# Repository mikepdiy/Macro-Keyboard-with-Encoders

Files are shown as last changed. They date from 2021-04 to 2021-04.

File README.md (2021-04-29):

<h1> Macro-Keyboard-with-Encoders</h1>
<br>
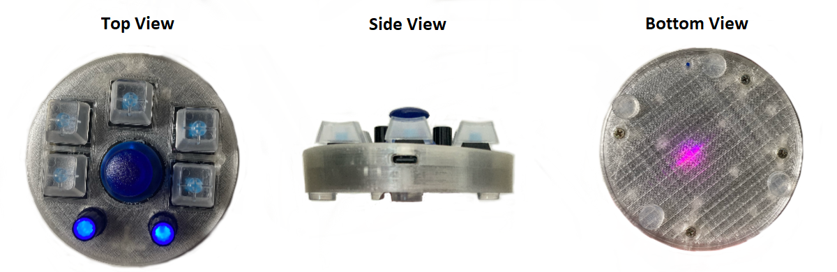
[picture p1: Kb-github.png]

<br>
<h3> Introduction and background </h3>
<br>
<br>
The idea to make this macro keyboard came to me when I was learning CAD and I found myself needing to use multiple keys shortcuts that included also middle mouse button presses for orbiting around the 3D object.
That was the moment when I went out to search for an accessory that can ease my life but to my surprise what was available on the market was also quite expensive to the point that I felt it was not worth it as I am not a CAD/CAM designer by trade but I wanted to learn a skill to aid my maker skill set. So what's the next thing a maker will do ? Indeed a maker will make it's own spin of an accessory. <br>
When making this keyboard I wanted to build something that fulfilled a few requirements :
<ul>
  <li> Easy to use for any user with out without technical knowledge</li>
  <li> Easy to set and use on any common Operating System ( Windows/MacOS/Linux ... ) </li>
  <li> No special software required to change the key's functionality</li>
  <li> Multiple key presses combined with mouse key presses on a single key </li>
  <li> Multiple ways of controlling the mouse pointer</li>
  <li> Open source as much as possible at least on the software side </li>
  <li> Hackable for the user that wants to do that without any special tools at least for the software side</li>
  <li> 3D printable case for the users that want to customize it</li>
  <li> Open source STL file of the board so the users can build their own spin of the case </li>
</ul>

<h3> What does this keyboard offer ?</h3>

<h4> Hardware </h4>
<ul>
  <li> 5 x MX Key Blue switches ( soldered to the PCB)</li>
  <li> 2 x Rotary encoders with 24 positions per rotation, push button function(click) if it is pressed and a blue led illumination. Left is for horizontal mouse pointer movement and Right is vertical mouse pointer movement</li>
  <li> 1 x Analog Joystick with push button function </li>
  <li> Type-C USB port that works correctly with type-C to type-C cables or type-C to USB-A cables </li>
  <li> Reset button on the bottom to allow quick software upgrade with drag and drop files</li>
  <li> Lightweight Design</li>
</ul>
<br>
<h4> Software </h4>
 <ul>
  <li> Based on open source bootloader and libraries </li>
  <li> Easy configuration by editing a text file for each individual button</li>
  <li> It can act as a <b>shortcut keyboard</b> => no matter how long you press the button it only clicks once </li>
  <li> It can act as a <b>keyboard</b> => as long as you keep a button pressed the programmed buttons in the configuration file will be pressed; example : in Fusion360 oribiting around a 3D object is done by holding pressed SHIFT+Mouse Middle Button and moving the mouse pointer; this can be achieved by keeping pressed one button on the macro keyboard and moving: your own mouse, the joystick on the macro keyboard or the rotary encoders  </li>
  <li> 2 firmware versions, one for <b> Shortcut keyboard </b> functionality and one for <b> Keyboard functionality </b> .</li>
  <li> In both firmware versions the keyboard can also type text for you i.e.: in case you want to use to type frequently used phrase or passowrd <b>(It's NOT SAFE to save your password in a shortcut keyboard and use it like this but sometimes convenience wins and the option is here but it's your choice if you want to use it or not)</b></li>
  <li> Access to the source code that was written for the Arduino IDE but it can be used in other IDE's</li>
  <li> .uf2 firmware releases with the original firmware released by me but also future updates in case there will be bugs that need to be fixed.</li>
  <li> For developers, this board also comes with exposed SWD interface that can be used if you need to </li>
  </ul>
  
 <h4> Included in this Repo </h4> 
  <ul>
    <li> Schematic </li>
    <li> Code for Arduino </li>
    <li> Bootloader </li>
    <li> .step board 3D file </li>
    <li> .stl 3D printable case that can be printed with FDM printers with 0.2mm layer height, 0.4mm nozzle and 30% infill using PLA </li>
  </ul>

  <h4> Tempted to grab one for yourself ? </h4>

  
  
<h4> Credits for the software side </h3>
  <ul>
  <li> <a href="https://github.com/adafruit">Adafruit Industries</a> - for their amazing work and tools that they provide for anyone to learn and enchance their skills</li>
  <li> <a href="https://github.com/danionescu0/arduino">Danionescu0</a> - for the helpful work done on parsing text files from an external storage in very short time </li>
  <li> Creators and contribuitors of the <a href="https://github.com/thomasfredericks/Bounce2">Bounce 2 library</a></li>
  <li> Creators and contribuitors of the <a href="https://github.com/mprograms/SimpleRotary">Simple Rotary library</a></li>
  <li> The creator of <a href="https://github.com/blurfl/makeUF2-tool/releases">MakeUF2-tool</a> </li>
 </ul>

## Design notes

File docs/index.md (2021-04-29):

## Welcome to the MacroKB web resources page

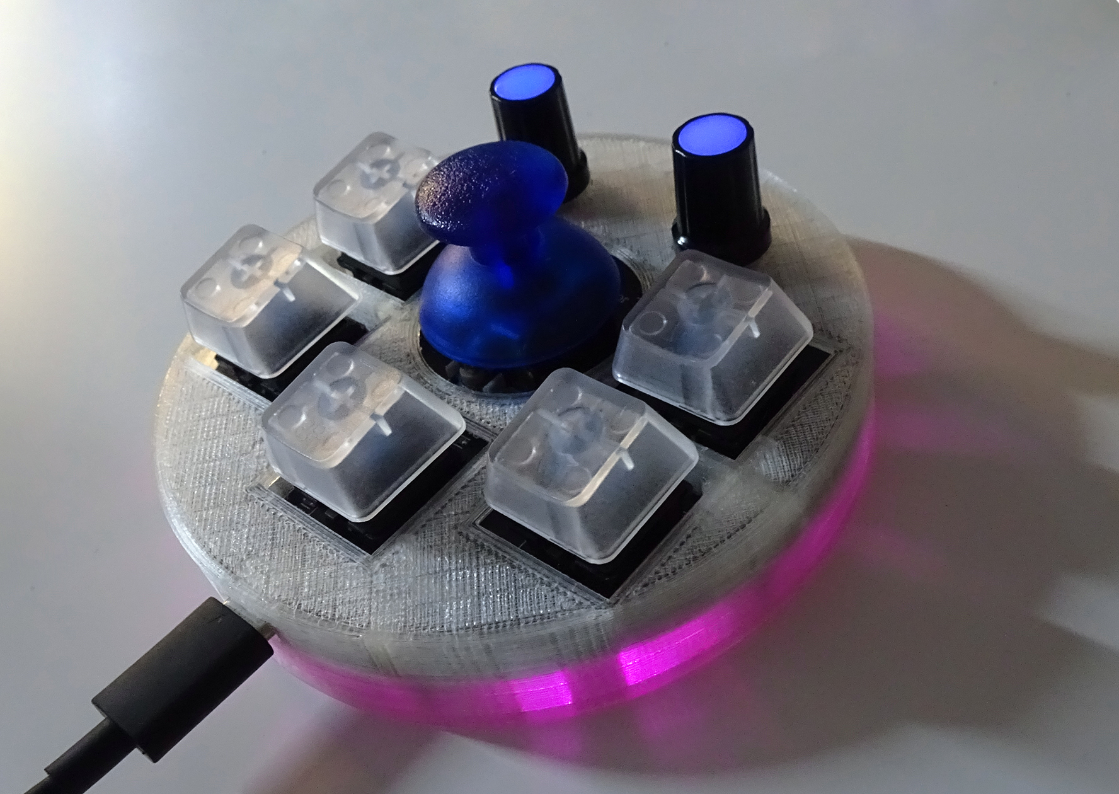
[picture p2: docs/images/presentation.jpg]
Presentation image


## The user manual can be found  [here](manual.md).

### More details are present in the Github repository [here](https://github.com/mikepdiy/Macro-Keyboard-with-Encoders/)

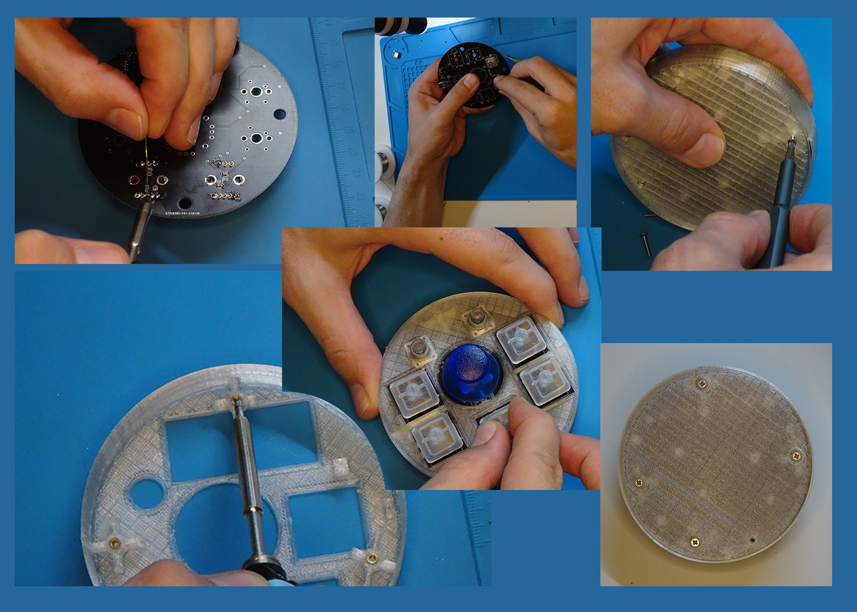
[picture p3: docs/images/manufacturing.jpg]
Manufacturing image


  <h4> Tempted to grab one for yourself ? </h4>

  

### More details to be added soon

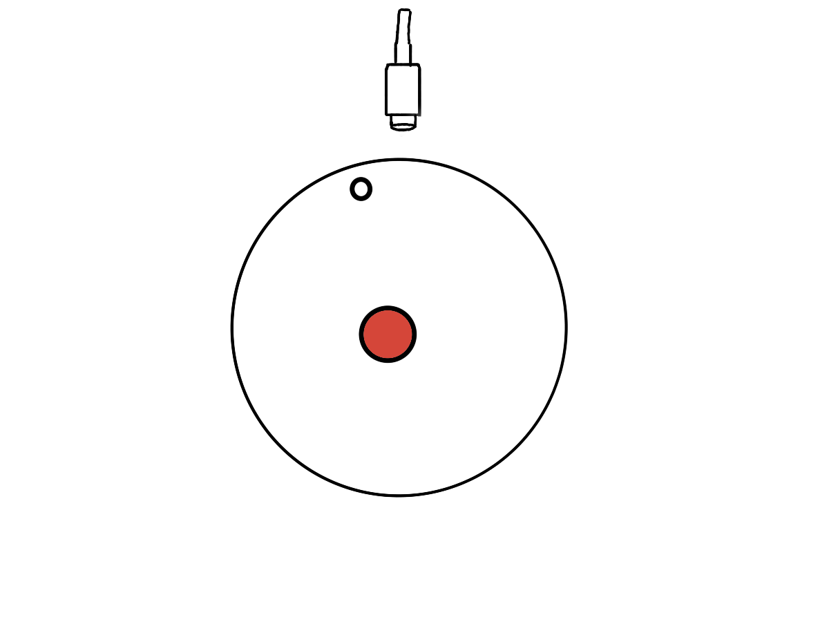
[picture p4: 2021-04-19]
docs/images/Red.png

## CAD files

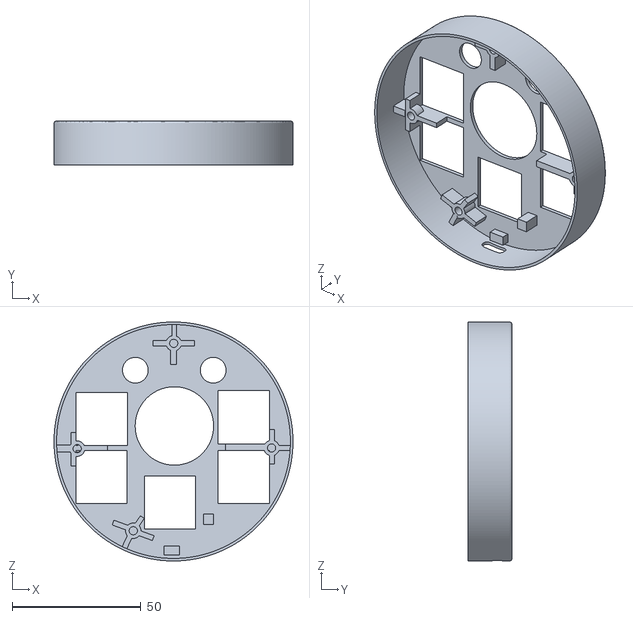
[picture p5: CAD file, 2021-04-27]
Case files/STL/top_case.stl
93.0 x 17.2 x 93.0

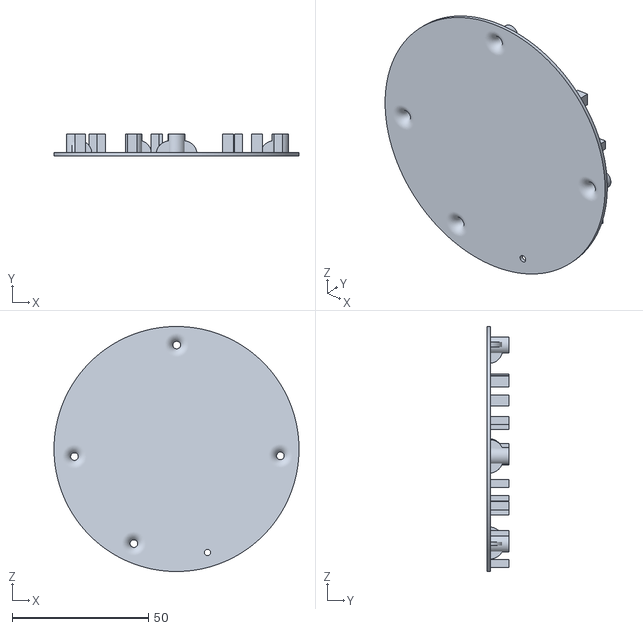
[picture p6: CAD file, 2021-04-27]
Case files/STL/bottom_case.stl
90.0 x 8.00 x 90.0

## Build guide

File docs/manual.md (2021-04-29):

## Thank you for supporting our project and deciding to grab our very first macro keyboard !

Overall image

```markdown
External Features / Components :

The macro keyboard has the following interfaces : 

    5 x MX-Key Blue switches

    1 x Analog Joystick (with switch functionality , it acts as a button when you press it )

    2 x Rotary Encoders (with switch functionality , it acts as a button when you press it )

    1 x Reset Button 

    1 x Type-C USB connector ( receptacle )

Supported Operating Systems : 

Any operating system that supports a keyboard can be used with our keyboard.
    
Works also with type-c to type-c cables ! (Who thought this is a feature ? :)) ) 
```
### Above Image

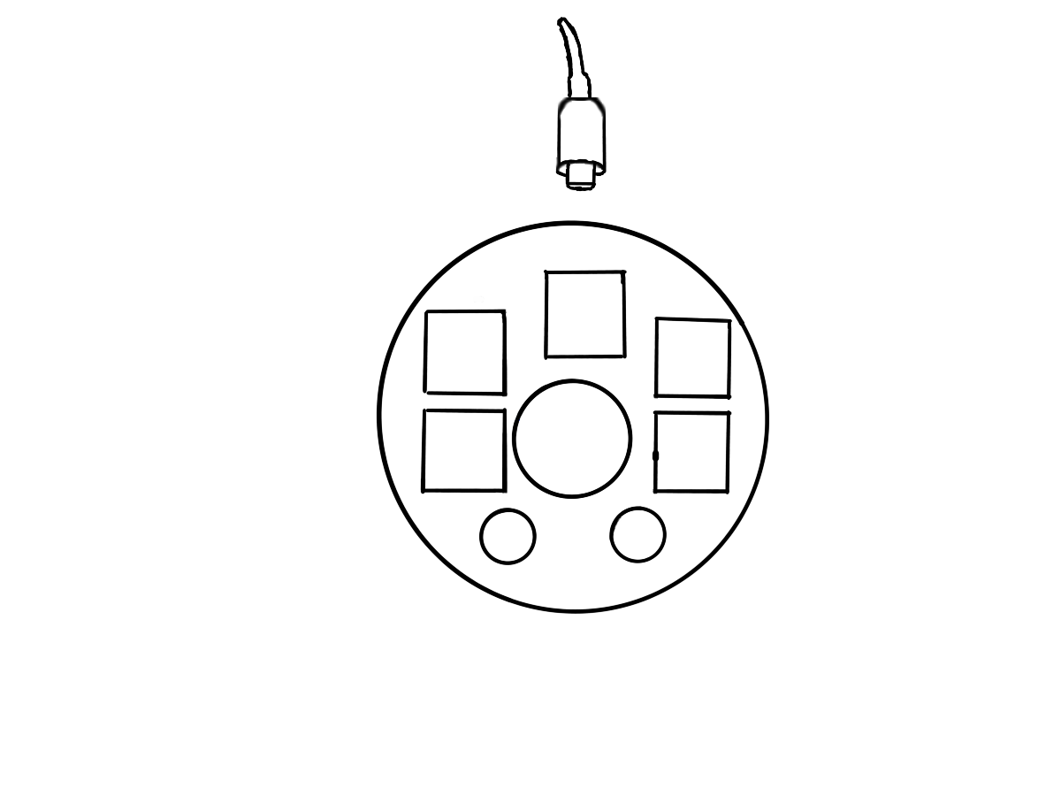
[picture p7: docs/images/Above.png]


### Encoders 

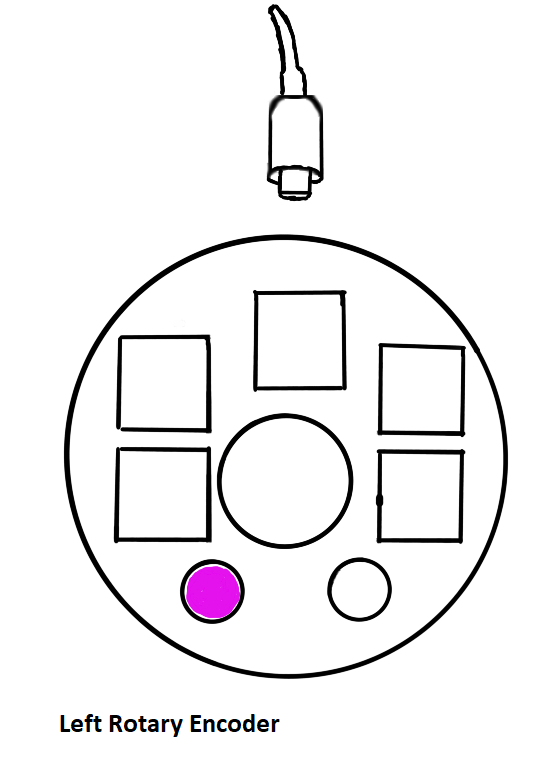
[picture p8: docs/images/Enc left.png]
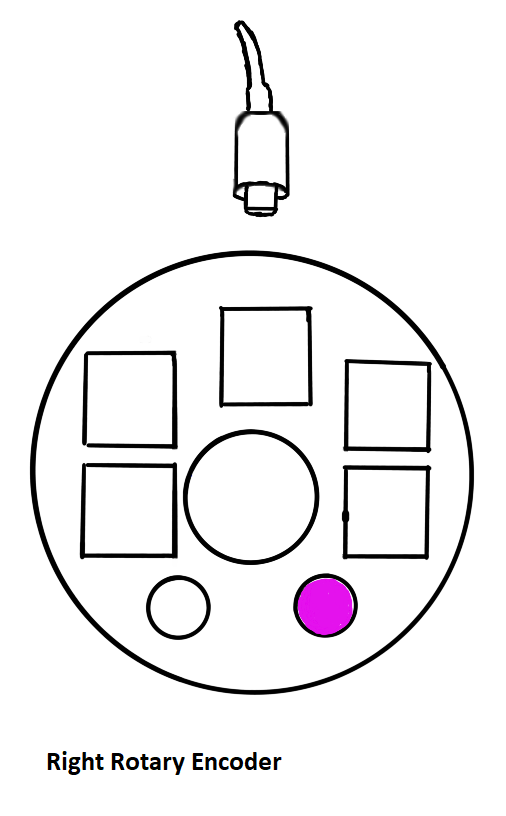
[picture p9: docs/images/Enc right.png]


```markdown
The Left Rotary Encoder moves the mouse pointer `Horizontally`. 
The Right Rotary Encoder moves the mouse pointer `Vertically`. 
```

### How to change the buttons configuration/functionality :

In order to use our macro keyboard you have to configure each button to do what you want it to do. This is actually very simple and it is a process you only have to do once . In case anything goes wrong, you can always restore the original files and start again.

### Configuration Steps : 

1. press the configuration button ( top middle button) and while you are keeping the button pressed, insert the usb cable that is connected to your pc.  
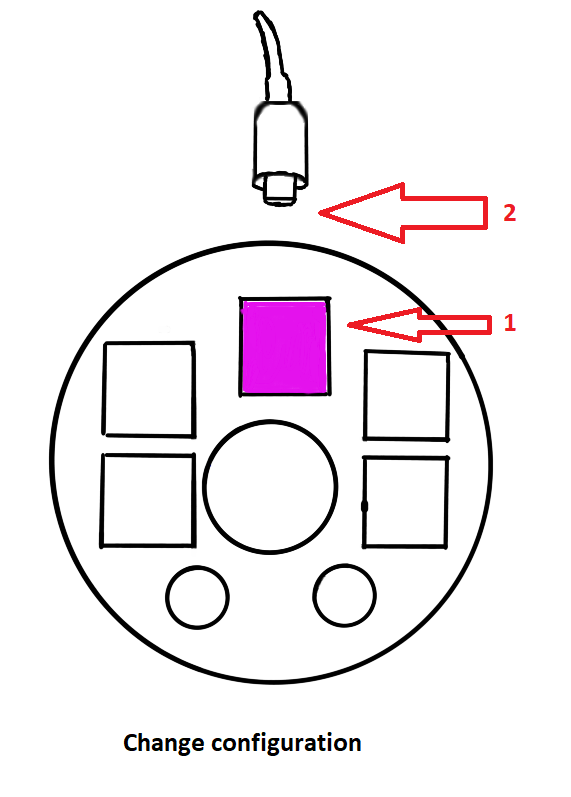
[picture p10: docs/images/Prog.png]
  

2. once the cable is connected to your pc the configuration button can be released and in a few seconds a new drive will appear in your file manager or “Computer” ( just like a new USB stick appears when you connect it to your computer).See the image below as an example :  
USB Drive  

 *If this is the first time you are connecting the keyboard to your computer, it might take a short while to install drivers .* 
 
 3.By opening and accessing the new disk that just appeared you will see a list of 6 ( six) text files that are named corresponding to the key position that each one of them controls. Please see the image below :  
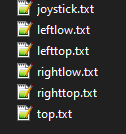
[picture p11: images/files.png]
files Drive
   
 
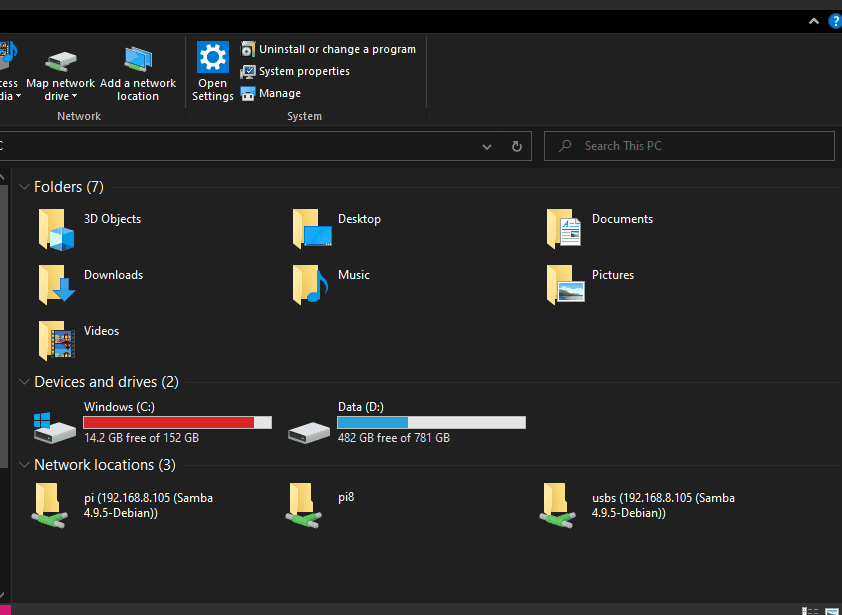
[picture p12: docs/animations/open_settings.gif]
Open Settings
  

 4. In order to change the configuration, you will have to open the file and edit the function(s) that the button will perform . Let’s open the file by double clicking on the button name.  
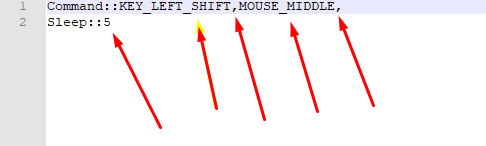
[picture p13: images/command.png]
Command example
   
 
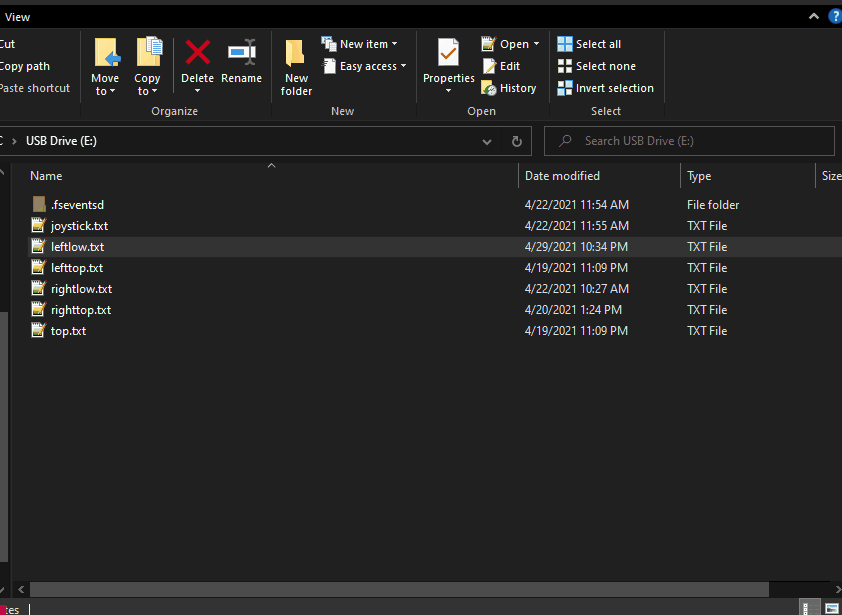
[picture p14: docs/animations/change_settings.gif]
Edit a command
    
 The first row starts with *Command::* and after that we have each key separated by comma ``` , ``` please put a comma ``` , ``` after each command and take note that the commands are executed in order.  We will explain the commands possible separately in the Keyboard Commands chapter. You can easily set 3 keys to be pressed at once but more than that is also possible.  

The commands can also be combined with letters ; for example : ``` Command:: KEY_LEFT_CTRL,p, ``` will bring up the print menu in Windows and Linux while ```Command:: KEY_LEFT_ALT,p,``` will open the print menu on MacOs.  

The example below does the following : Simulate SHIFT key press and while SHIFT is pressed it will simulate the press of the Mouse Middle key , this is what is needed for Autodesk Fusion 360 to allow orbiting around a 3D file.   

The second row starts with *Sleep::* and this allows you to set a very short break that is counted in milliseconds in case your computer doesn’t register all the key presses that you have set. The Sleep function just allows a short amount of time for the computer to register each button press and it should be used like this :  

```markdown
Command::KEY_LEFT_SHIFT,
Sleep::5
Command::MOUSE_MIDDLE,
```
#### Don’t use the *Sleep::* function unless you need it !

### Other examples :
 
Copy Functionality on Windows : 

```markdown
Command::KEY_LEFT_CTRL,
c
```

Paste Functionality for Windows : 
```markdown
Command::KEY_LEFT_CTRL,
v
```

6 - Save the file and you can edit another file or allow 30 seconds, then you can disconnect and reconnect the USB cable. Now you are ready to use your macro keyboard.  </br>

### Restore the original files : 

### Situation A - the configuration files can’t be edited/opened

If your configuration files get damaged you just need to repeat the configuration steps 1 to 3 and then copy the original configuration files that you can download from <a href="https://github.com/mikepdiy/Macro-Keyboard-with-Encoders/tree/main/Config%20Files">here</a>.

### Situation B - My keyboard doesn’t come up as a USB disk anymore

The easiest way to solve this problem is by reflashing the firmware ; to do this please connect the USB cable to your pc and then double press the reset button. Once the button was pressed 2 times, the LED on the bottom on the keyboard will turn **GREEN** and the keyboard will appear as a USB disk with the name : **MAKERKB** . Now you can copy the firmware file that you can download from <a href="https://github.com/mikepdiy/Macro-Keyboard-with-Encoders/tree/main/Code%20V0.1/Bootloader">here</a> to the keyboard (just drag and drop) and it will reflash itself and update.  

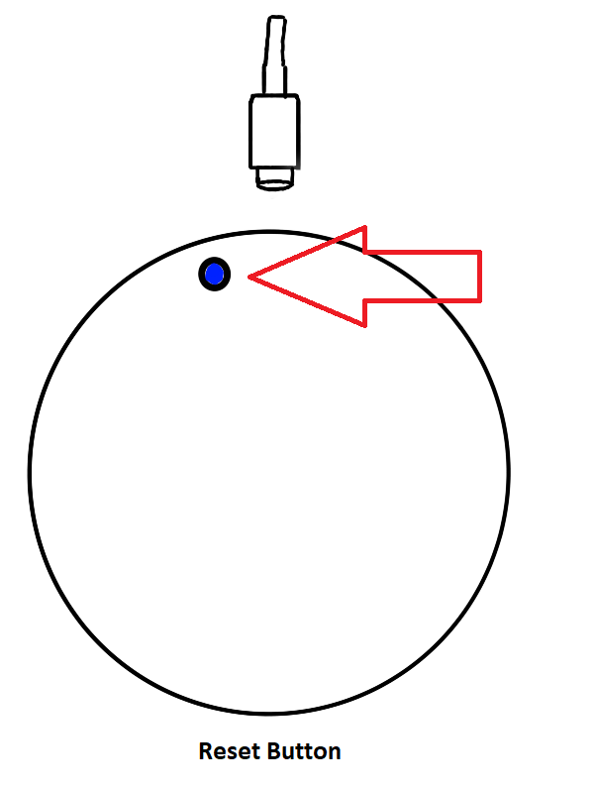
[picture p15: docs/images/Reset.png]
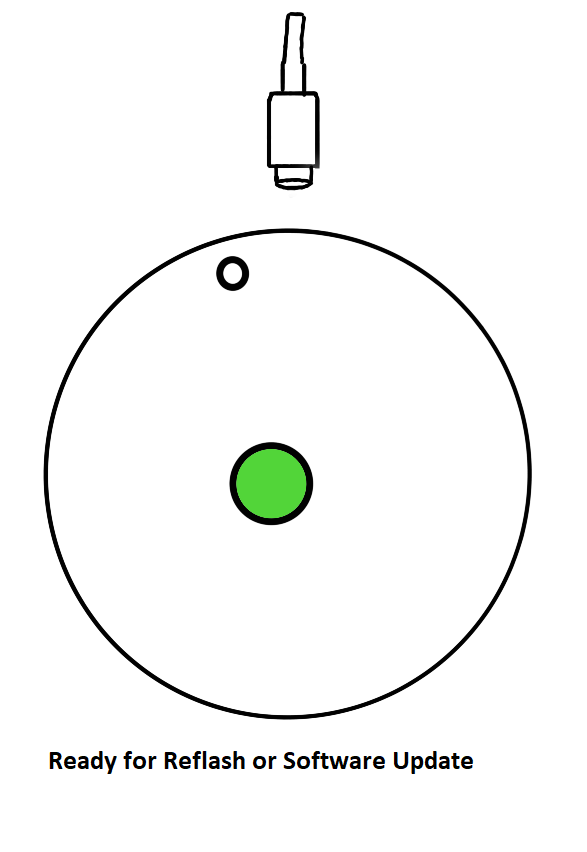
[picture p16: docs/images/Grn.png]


#### NOTICE: Please don’t disconnect the keyboard from your PC until the flashing process is done, this can take up to 2 minutes (120 seconds) . 

### KEYBOARD COMMANDS : 

<table>
  <tr>
    <th>Command::</th>
    <th>Function</th>
  </tr>
  <tr>
    <td>KEY_LEFT_CTRL</td>
    <td>CTRL</td>
  </tr>
    <tr>
    <td>KEY_LEFT_GUI</td>
    <td>Windows Key</td>
  </tr>
    </tr>
    <tr>
    <td>KEY_CMD</td>
    <td>MacOS Left CMD Key</td>
  </tr>
      <tr>
    <td>KEY_OPT</td>
    <td>MacOS Left ALT KEY</td>
  </tr>
    <tr>
    <td>KEY_LEFT_ALT</td>
    <td>Left Alt</td>
  </tr>
    <tr>
    <td>KEY_UP_ARROW</td>
    <td>Arrow Up</td>
  </tr>
      <tr>
    <td>KEY_DOWN_ARROW</td>
    <td>Arrow Down</td>
  </tr>
      <tr>
    <td>KEY_LEFT_ARROW</td>
    <td>Arrow Left</td>
  </tr>
      <tr>
    <td>KEY_RIGHT_ARROW</td>
    <td>Right Up</td>
  </tr>
      <tr>
    <td>KEY_RIGHT_GUI</td>
    <td>Right GUI ( not commonly needed)</td>
  </tr>
        <tr>
    <td>KEY_BACKSPACE</td>
    <td>Backspace</td>
  </tr>
          <tr>
    <td>KEY_TAB</td>
    <td>Tab</td>
  </tr>
          <tr>
    <td>KEY_RETURN</td>
    <td>Retrun / Enter</td>
  </tr>
          <tr>
    <td>KEY_ESC</td>
    <td>Esc</td>
  </tr>
          <tr>
    <td>KEY_INSERT</td>
    <td>Insert</td>
  </tr>
          <tr>
    <td>KEY_DELETE</td>
    <td>Delete</td>
  </tr>
          <tr>
    <td>KEY_PAGE_UP</td>
    <td>Page Up</td>
  </tr>
          <tr>
    <td>KEY_PAGE_DOWN</td>
    <td>Page down</td>
  </tr>
          <tr>
    <td>KEY_HOME</td>
    <td>HOME</td>
  </tr>
          <tr>
    <td>KEY_END</td>
    <td>END</td>
  </tr>
          <tr>
    <td>KEY_F1</td>
    <td>F1</td>
  </tr>
            <tr>
    <td>KEY_F2</td>
    <td>F2</td>
  </tr>
            <tr>
    <td>KEY_F3</td>
    <td>F3</td>
  </tr>
            <tr>
    <td>KEY_F4</td>
    <td>F4</td>
  </tr>
            <tr>
    <td>KEY_F5</td>
    <td>F5</td>
  </tr>
            <tr>
    <td>KEY_F6</td>
    <td>F6</td>
  </tr>
            <tr>
    <td>KEY_F7</td>
    <td>F7</td>
  </tr>
            <tr>
    <td>KEY_F8</td>
    <td>F8</td>
  </tr>
            <tr>
    <td>KEY_F9</td>
    <td>F9</td>
  </tr>
            <tr>
    <td>KEY_F10</td>
    <td>F10</td>
  </tr>
            <tr>
    <td>KEY_F11</td>
    <td>F11</td>
  </tr>
            <tr>
    <td>KEY_F12</td>
    <td>F12</td>
  </tr>
            <tr>
    <td>MOUSE_LEFT</td>
    <td>Mouse LEFT Click</td>
  </tr>
              <tr>
    <td>MOUSE_RIGHT</td>
    <td>Mouse RIGHT Click</td>
  </tr>
            <tr>
    <td>MOUSE_MIDDLE</td>
    <td>Mouse MIDDLE Click</td>
  </tr>
  </table>

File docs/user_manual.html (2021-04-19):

# Thank you for supporting our project and deciding to grab our very first macro keyboard !

over all

External Features / Components :

The macro keyboard has the following interfaces :

- 5 x MX-Key Blue switches
- 1 x Analog Joystick (with switch functionality , it acts as a button when you press it )
- 2 x Rotary Encoders (with switch functionality , it acts as a button when you press it )
- 1 x Reset Button
- 1 x Type-C USB connector ( receptacle )

Supported Operating Systems :

- Any operating system that supports a keyboard and be used with our keyboard

Software needed for Windows :

- Notepad++ [add link]



 

The Left Rotary Encoder moves the mouse pointer Horizontally while the Right Rotary Encoder moves the mouse pointer Vertically.

## How to change the buttons configuration/functionality :

In order to use our macro keyboard you have to configure each button to do what you want it to do. This is actually very simple and it is a process you only have to do once . In case anything goes wrong, you can always restore the original files and start again.

Configuration Steps :

1 - press the configuration button ( top middle button) and while you are keeping the button pressed, insert the usb cable that is connected to your pc.



2 - once the cable is connected to your pc the configuration button can be released and in a few seconds a new drive will appear in your file manager or “Computer” ( just like a new USB stick appears when you connect it to your computer).See the image below as an example :



*If this is the first time you are connecting the keyboard to your computer, it might take a short while to install drivers .

3 - By opening and accessing the new disk that just appeared you will see a list of 6 ( six) text files that are named corresponding to the key position that each one of them controls. Please see the image below :



4 - In order to change the configuration, you will have to open the file and edit the function(s) that the button will perform . Let’s open the file by double clicking on the button name.

5 - Now that the files is open you can check or change the functionality.



The first row starts with “Command::” and after that we have each key separated by comma (,) , please put a comma (,) after each command and take note that the commands are executed in order. We will explain the commands possible separately in the Keyboard Commands chapter. You can easily set 3 keys to be pressed at once but more than that is also possible.

The commands can also be combined with letters ; for example : Command:: KEY_LEFT_CTRL,p, will bring up the print menu in Windows and Linux while Command:: KEY_LEFT_ALT,p, will open the print menu on MacOs.

The example given here does the following : Simulate SHIFT key press and while SHIFT is pressed it will simulate the press of the Mouse Middle key , this is what is needed for Autodesk Fusion 360 to allow orbiting around a 3D file.

The second row starts with “Sleep::” and this allows you to set a very short break that is counted in milliseconds in case your computer doesn’t register all the key presses that you have set. The Sleep function just allows a short amount of time for the computer to register each button press and it should be used like this :

Command::KEY_LEFT_SHIFT,

Sleep::5

Command::MOUSE_MIDDLE,

Don’t use it unless you need it !

6 - Save the file and you can edit another file or allow 30 seconds, then you can disconnect and reconnect the USB cable. Now you are ready to use your macro keyboard.

Restore the original files :

Situation A - the configuration files can’t be edited/opened

If your configuration files get damaged you just need to repeat the configuration steps 1 to 3 and then copy the original configuration files that you can download from LINK

Situation B - My keyboard doesn’t come up as a USB disk anymore

The easiest way to solve this problem is by reflashing the firmware ; to do this please connect the USB cable to your pc and then double press the reset button. Once the button was pressed 2 times, the LED on the bottom on the keyboard will turn GREEN and the keyboard will appear as a USB disk with the name : ITSYBOOT . Now you can copy the firmware file that you can download from LINK to the keyboard and it will reflash itself and update.

 

NOTICE: Please don’t disconnect the keyboard from your PC until the flashing process is done, this can take up to 2 minutes (120 seconds) .

Keyboard Commands :

Command:: | Function
KEY_LEFT_CTRL | CTRL
KEY_LEFT_GUI | Windows key/Opt/Super
KEY_LEFT_SHIFT | Shift
KEY_LEFT_ALT | ALT / CMD
KEY_UP_ARROW | Arrow UP
KEY_DOWN_ARROW | Arrow DOWN
KEY_LEFT_ARROW | Arrow LEFT
KEY_RIGHT_ARROW | Arrow RIGHT
KEY_RIGHT_GUI | Right GUI ( very rarely used)
KEY_BACKSPACE | Backspace
KEY_TAB | TAB
KEY_RETURN | Return / Enter
KEY_ESC | ESC
KEY_INSERT | Insert
KEY_DELETE | Delete
KEY_PAGE_UP | Page UP
KEY_PAGE_DOWN | Page Down
KEY_HOME | Home
KEY_END | End
KEY_CAPS_LOCK | Caps Lock
KEY_F1 | F1
KEY_F2 | F2
KEY_F3 | F3
KEY_F4 | F4
KEY_F5 | F5
KEY_F6 | F6
KEY_F7 | F7
KEY_F8 | F8
KEY_F9 | F9
KEY_F10 | F10
KEY_F11 | F11
KEY_F12 | F23
MOUSE_LEFT | Mouse Left Button
MOUSE_RIGHT | Mouse Right Button
MOUSE_MIDDLE | Mouse Middle Button

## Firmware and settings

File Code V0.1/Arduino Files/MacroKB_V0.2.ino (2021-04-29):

/*
===============================================================================================================
Libraries used that can be difficult to identify just by name : 
Simple Rotary : https://github.com/mprograms/SimpleRotary
Bounce2 : https://github.com/thomasfredericks/Bounce2

===============================================================================================================

History:
v0.2 - cleaned up the code and released it to Github
v0.1 - functions implemented and text file names changed to sensible values 


*/
//#define BOUNCE_LOCK_OUT
#include "SPI.h"
#include "SdFat.h"
#include "Adafruit_SPIFlash.h"
#include "Adafruit_TinyUSB.h"
#include <TinyUSB_Mouse_and_Keyboard.h>
#include <SimpleRotary.h>
#include <Bounce2.h>
#include <ctype.h>

//Definition of the variables

String filenameOnCard1 = "leftlow.txt";
String filenameOnCard2 = "lefttop.txt";
String filenameOnCard3 = "top.txt";
String filenameOnCard4 = "righttop.txt";
String filenameOnCard5 = "rightlow.txt";
String filenameOnCard6 = "joystick.txt";
String sleepCommandStartingPoint = "Sleep::";
String commandStartingPoint = "Command::";
int delayBetweenCommands = 1;
      
//Define buttons pins
#define SW1 2
#define SW2 5
#define SW3 11
#define SW4 7
#define SW5 6
#define SW6 A3


// INSTANTIATE A Button OBJECT FROM THE Bounce2 NAMESPACE
Bounce2::Button button1 = Bounce2::Button();
Bounce2::Button button2 = Bounce2::Button();
Bounce2::Button button3 = Bounce2::Button();
Bounce2::Button button4 = Bounce2::Button();
Bounce2::Button button5 = Bounce2::Button();
Bounce2::Button button6 = Bounce2::Button();


//Debounce the rotary encoders pins
Bounce encst = Bounce(9, 10);//enc left button
Bounce encdr = Bounce(3, 10);//enc right button

//Define Keys aliases
char shiftKey = KEY_LEFT_SHIFT;
char ctrlKey = KEY_LEFT_CTRL;

//used to store scroll factor for rotary encoders
byte p = 5;



//used to store scroll value High or Low
int encClickFlag = 0;

// Definition of the rotary encoders (Pin A, Pin B, Button Pin)
SimpleRotary rotary(8,A4,9); //left encoder
SimpleRotary rotary2(4,1,3); // right encoder
Bounce encst1 = Bounce(8, 10);//enc left button
Bounce encst2 = Bounce(A4, 10);//enc right button
Bounce encdr1 = Bounce(4, 10);//enc left button
Bounce encdr2 = Bounce(1, 10);//enc right button

//mass storage flash related
#if defined(FRAM_CS) && defined(FRAM_SPI)
  Adafruit_FlashTransport_SPI flashTransport(FRAM_CS, FRAM_SPI);

#else
  // On-board external flash (QSPI or SPI) macros should already
  // defined in your board variant if supported
  // - EXTERNAL_FLASH_USE_QSPI
  // - EXTERNAL_FLASH_USE_CS/EXTERNAL_FLASH_USE_SPI
  #if defined(EXTERNAL_FLASH_USE_QSPI)
    Adafruit_FlashTransport_QSPI flashTransport;

  #elif defined(EXTERNAL_FLASH_USE_SPI)
    Adafruit_FlashTransport_SPI flashTransport(EXTERNAL_FLASH_USE_CS, EXTERNAL_FLASH_USE_SPI);

  #else
    #error No QSPI/SPI flash are defined on your board variant.h !
  #endif
#endif

Adafruit_SPIFlash flash(&flashTransport);

// file system object from SdFat
FatFileSystem fatfs;

FatFile root;
FatFile file;

// USB Mass Storage object
Adafruit_USBD_MSC usb_msc;

// Set to true when PC write to flash
bool changed;
//Joystick Axis and sensitivity
int horzPin = A2;  // Analog output of horizontal joystick pin
int vertPin = A1;  // Analog output of vertical joystick pin

int vertZero, horzZero;  // Stores the initial value of each axis, usually around 512
int vertValue, horzValue;  // Stores current analog output of each axis
const int sensitivity = 100;  // Higher sensitivity value = slower mouse, should be <= about 500

void setup() {

//finalize the BOUNCE2 Library insert

encst.attach(9, INPUT);
encst.interval(5);
encdr.attach(3, INPUT);
encdr.interval(5);
encst1.attach(8, INPUT);
encst1.interval(5);
encst2.attach(A4, INPUT);
encst2.interval(5);
encdr1.attach(4, INPUT);
encdr1.interval(5);
encdr2.attach(1, INPUT);
encdr2.interval(5);
//Button setup
button1.attach( SW1, INPUT );
button2.attach( SW2, INPUT );
button3.attach( SW3, INPUT );
button4.attach( SW4, INPUT );
button5.attach( SW5, INPUT );
button6.attach( SW6, INPUT );
// DEBOUNCE INTERVAL IN MILLISECONDS
  button1.interval(5);
  button2.interval(5);
  button3.interval(15);
  button4.interval(5);
  button5.interval(5);
  button6.interval(5);
// INDICATE THAT THE LOW STATE CORRESPONDS TO PHYSICALLY PRESSING THE BUTTON
  button1.setPressedState(LOW); 
  button2.setPressedState(LOW); 
  button3.setPressedState(LOW); 
  button4.setPressedState(LOW); 
  button5.setPressedState(LOW); 
  button6.setPressedState(LOW); 


  //defining the pins
  pinMode(9, INPUT);//left encoder click
  pinMode(3, INPUT);//right encoder click
  pinMode(1, INPUT); //right enc
  pinMode(4, INPUT); // right enc
  pinMode(A4, INPUT);//left enc
  pinMode(8, INPUT);//left enc
  pinMode(horzPin, INPUT);  // Set both analog pins as inputs
  pinMode(vertPin, INPUT);


//Error delay fix rotary pins standard is 200 , the higher the better to avoid errors at direction change at the cost of quick direction change normallt 0 and 1 work fine for KB
    rotary.setErrorDelay(1); 
    rotary2.setErrorDelay(1); 
//Debounce rotary pins standard is 2 , the higher the better to avoid errors but will be at cost of missing pulses  
    rotary.setDebounceDelay(2);
    rotary2.setDebounceDelay(2);


  //mass storage flash related
  flash.begin();
 

  // Set disk vendor id, product id and revision with string up to 8, 16, 4 characters respectively
  usb_msc.setID("DLM", "MacroKB Flash", "1.0");

  // Set callback
  usb_msc.setReadWriteCallback(msc_read_cb, msc_write_cb, msc_flush_cb);

  // Set disk size, block size should be 512 regardless of spi flash page size
  usb_msc.setCapacity(flash.size()/512, 512);

  // MSC is ready for read/write
  usb_msc.setUnitReady(true);

//mount USB Drive to host in order to change config only when Middle Top button is pressed
  if(digitalRead(11)==LOW){
  usb_msc.begin();
  }
  else{
  
  }

  // Init file system on the flash
  fatfs.begin(&flash);
  
  Keyboard.begin();
  Mouse.begin();
  vertZero = analogRead(vertPin);  // get the initial values
  horzZero = analogRead(horzPin);  // Joystick should be in neutral position when reading these

  
  Serial.begin(115200);
  Serial.println("Mass storage device connected and mounted");
  Serial.print("JEDEC ID: "); Serial.println(flash.getJEDECID(), HEX);
  Serial.print("Flash size: "); Serial.println(flash.size());

  changed = true; // to print contents initially

  
}

void loop() {
//Joystick Mouse
  vertValue = analogRead(vertPin) - vertZero;  // read vertical offset
  horzValue = analogRead(horzPin) - horzZero;  // read horizontal offset
  
  if (vertValue != 0)
    Mouse.move(0, -vertValue/sensitivity, 0);  // move mouse on y axis
  if (horzValue != 0)
    Mouse.move(-horzValue/sensitivity, 0, 0);  // move mouse on x axis

// refresh/update keys status


button1.update();
button2.update();
button3.update();
button4.update();
button5.update();
button6.update();
encst.update();
encdr.update();
encst1.update();
encst2.update();
encdr1.update();
encdr2.update();


if (button1.fell()) {
  sdFileToKeyboard1();

}
else if (button1.rose()){
    Keyboard.releaseAll();
    delay(1);
    Mouse.releaseAll();
    delay(1);
}


if (button2.fell()) {
 sdFileToKeyboard2();
 
}

else if (button2.rose()){
    Keyboard.releaseAll();
    delay(1);
    Mouse.releaseAll();
    delay(1);

}

if (button3.fell()){
  sdFileToKeyboard3();

}

else if (button3.rose()){
    Keyboard.releaseAll();
    delay(1);
    Mouse.releaseAll();
    delay(1);

}

if (button4.fell()) {

sdFileToKeyboard4();
  
}
else if (button4.rose()){
    Keyboard.releaseAll();
    delay(1);
    Mouse.releaseAll();
    delay(1);

}

if (button5.fell()) {
sdFileToKeyboard5();

}
else if (button5.rose()){
    Keyboard.releaseAll();
    delay(1);
    Mouse.releaseAll();
    delay(1);

}

if (button6.fell()) {
sdFileToKeyboard6();

}
else if (button6.rose()){
    Keyboard.releaseAll();
    delay(1);
    Mouse.releaseAll();
    delay(1);

}

  
  byte i; //left encoder
  byte x; // right encoder

  // 0 = not turning, 1 = CW, 2 = CCW
  i = rotary.rotate(); //update value left encoder
  x = rotary2.rotate(); // update value right encoder
  if ( i == 1 ) {
    Serial.println("CW");
     Mouse.move(+5*p,0,0);
  }

  if ( i == 2 ) {
    Serial.println("CCW");
     Mouse.move(-5*p, 0,0);
  }
   
   if ( x == 1 ) {
    Serial.println("CW");
     Mouse.move(0,+5*p,0);
  }

  if ( x == 2 ) {
    Serial.println("CCW");
     Mouse.move(0, -5*p,0);
  }
//loop closing below   
}

//mass storage related


// Callback invoked when received READ10 command.
// Copy disk's data to buffer (up to bufsize) and 
// return number of copied bytes (must be multiple of block size) 
int32_t msc_read_cb (uint32_t lba, void* buffer, uint32_t bufsize)
{
  // Note: SPIFLash Bock API: readBlocks/writeBlocks/syncBlocks
  // already include 4K sector caching internally. We don't need to cache it, yahhhh!!
  return flash.readBlocks(lba, (uint8_t*) buffer, bufsize/512) ? bufsize : -1;
}

// Callback invoked when received WRITE10 command.
// Process data in buffer to disk's storage and 
// return number of written bytes (must be multiple of block size)
int32_t msc_write_cb (uint32_t lba, uint8_t* buffer, uint32_t bufsize)
{
 // digitalWrite(LED_BUILTIN, HIGH);

  // Note: SPIFLash Bock API: readBlocks/writeBlocks/syncBlocks
  // already include 4K sector caching internally. We don't need to cache it, yahhhh!!
  return flash.writeBlocks(lba, buffer, bufsize/512) ? bufsize : -1;
}

// Callback invoked when WRITE10 command is completed (status received and accepted by host).
// used to flush any pending cache.
void msc_flush_cb (void)
{
  // sync with flash
  flash.syncBlocks();

  // clear file system's cache to force refresh
fatfs.cacheClear();


 changed = true;

 // digitalWrite(LED_BUILTIN, LOW);
}

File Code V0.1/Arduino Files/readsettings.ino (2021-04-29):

void sdFileToKeyboard1() {
    File dataFile = fatfs.open(filenameOnCard1);
    if (!dataFile) {
      Serial.println("The specified filename is not present on the memory ic, check filenameOnCard !");
    }
    String line;
    while (dataFile.available()) {
        line = dataFile.readStringUntil('\n');
        Serial.println(line);
        sendToKeyboard(line);
    }
    dataFile.close();
}

void sdFileToKeyboard2() {
    File dataFile = fatfs.open(filenameOnCard2);
    if (!dataFile) {
      Serial.println("The specified filename is not present on the memory ic, check filenameOnCard !");
    }
    String line;
    while (dataFile.available()) {
        line = dataFile.readStringUntil('\n');
        Serial.println(line);
        sendToKeyboard(line);
    }
    dataFile.close();
}

void sdFileToKeyboard3() {
    File dataFile = fatfs.open(filenameOnCard3);
    if (!dataFile) {
      Serial.println("The specified filename is not present on the memory ic, check filenameOnCard !");
    }
    String line;
    while (dataFile.available()) {
        line = dataFile.readStringUntil('\n');
        Serial.println(line);
        sendToKeyboard(line);
    }
    dataFile.close();
}

void sdFileToKeyboard4() {
    File dataFile = fatfs.open(filenameOnCard4);
    if (!dataFile) {
      Serial.println("The specified filename is not present on the memory ic, check filenameOnCard !");
    }
    String line;
    while (dataFile.available()) {
        line = dataFile.readStringUntil('\n');
        Serial.println(line);
        sendToKeyboard(line);
    }
    dataFile.close();
}

void sdFileToKeyboard5() {
    File dataFile = fatfs.open(filenameOnCard5);
    if (!dataFile) {
      Serial.println("The specified filename is not present on the memory ic, check filenameOnCard !");
    }
    String line;
    while (dataFile.available()) {
        line = dataFile.readStringUntil('\n');
        Serial.println(line);
        sendToKeyboard(line);
    }
    dataFile.close();
}

void sdFileToKeyboard6() {
    File dataFile = fatfs.open(filenameOnCard6);
    if (!dataFile) {
      Serial.println("The specified filename is not present on the memory ic, check filenameOnCard !");
    }
    String line;
    while (dataFile.available()) {
        line = dataFile.readStringUntil('\n');
        Serial.println(line);
        sendToKeyboard(line);
    }
    dataFile.close();
}

void sendToKeyboard(String line) {
    String workingLine = line;
    if (workingLine.indexOf(sleepCommandStartingPoint) != -1) {
        sleepFor(line);
        return;      
    }
    if (workingLine.indexOf(commandStartingPoint) == -1) {
        Keyboard.print(line);
 
        
        return;        
    }    

    int charPosition = commandStartingPoint.length();
    int lineLength = line.length();
    workingLine += ",";

    
    while (workingLine != "") {
        workingLine = workingLine.substring(charPosition);
        int specialCommandDelimiterPosition = workingLine.indexOf(",");
        String command = workingLine.substring(0, specialCommandDelimiterPosition);
        charPosition = specialCommandDelimiterPosition + 1;
        if (command.startsWith("KEY", 0)) {
            Keyboard.press(getCommandCode(command));
            delay(delayBetweenCommands);
        }
        if (command.startsWith("MOUSE", 0)) {
            Mouse.press(getCommandCode(command));
            delay(delayBetweenCommands);
        }
    }


}

void pressEnter() {
    Keyboard.press(KEY_RETURN);
    Keyboard.releaseAll();
}

void sleepFor(String line) {
    int sleepAmount = line.substring(sleepCommandStartingPoint.length(), line.length()).toInt();
    Serial.print("Sleeping for:");Serial.println(sleepAmount);
    delay(sleepAmount);
}
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

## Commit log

2021-04-27 added 3D files
    [KB_Board_schematic.sch, bottom_case.stl, top_case.stl]
2021-04-29 small fix in v0.2
    [readsettings.ino]
